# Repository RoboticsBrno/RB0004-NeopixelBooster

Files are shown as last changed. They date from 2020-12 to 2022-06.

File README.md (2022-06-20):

# RB0004 - Neopixel Booster

Probably all of us makers love WS2812B - the addressable LEDs, which are often
called "Neopixel" based on the brand created by
[Adafruit](https://learn.adafruit.com/adafruit-neopixel-uberguide). They are so
much fun to play with! Especially when you can buy them in strips for less than
18 USD/5 meters!

These LEDs are, however, power-hungry, and the strips are not the best design.
Therefore you often struggle to power them - you need a 5V power supply with
a large current rating. And these aren't easy to get. And if you get one, the
strips behave weirdly - the end of the strip has more reddish colors compared
to it's beginning.

**This is where RB0004 - Neopixel Booster comes in: it solves all the problems
above.**

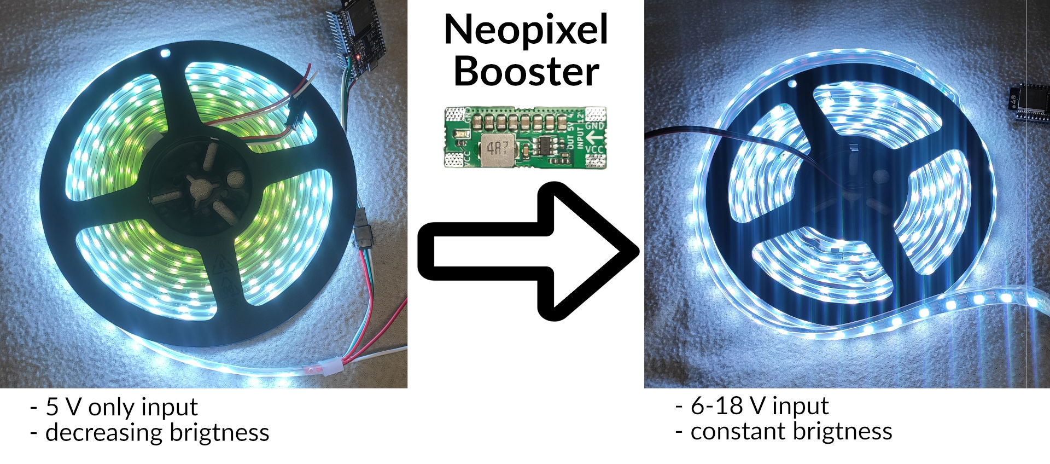
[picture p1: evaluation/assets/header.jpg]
Header


View this project on [CADLAB.io](https://cadlab.io/project/23122).

## The Problem In Short

If you are interested in much in-depth explanation of the problem with some
measurements, see the [page about strips properties](properties.md).

Each of the LEDs consumes around 60-70 mA in the full brightness (based on the
temperature and batch you have). Therefore, if you have 300 LEDs in a strip,
they will consume 18-21 A! That's a lot of current. When you push current
through a wire, there is a voltage drop according to [Ohm's
law](https://en.wikipedia.org/wiki/Ohm%27s_law). The copper wire on the strips
is relatively thin and narrow. Therefore, there will be a significant voltage
drop. It is quite common that you supply your strip with 5 V, but you will
measure only 2.5 V at the end of the strip. That means your LEDs can't shine the
full brightness.

But why they turn red? There is a red, green, and blue LED in the
chip. Each of the LED colors has a different [forward voltage
drop](https://en.wikipedia.org/wiki/LED_circuit) - the blue one has the larges
one, and it is usually around 3 V. That means if the LED is supplied with less
than 3V, it cannot light up the blue channel and thus, it is missing from the
final color.

You could solve that by just bonding a thick wire to the back of the strip.
However, a suitable wire for 21 A will be pretty thick (around 3.5 mm²).
Therefore, it is better to power the whole strip with higher voltage, thus
lower the current flowing in the wires and only lower the voltage locally for a
few LEDs. And that's what exactly Neopixel Booster does.

You run an extra wire around your LED strip and connect multiple Neopixel
Boosters in the strip to power it by segments:

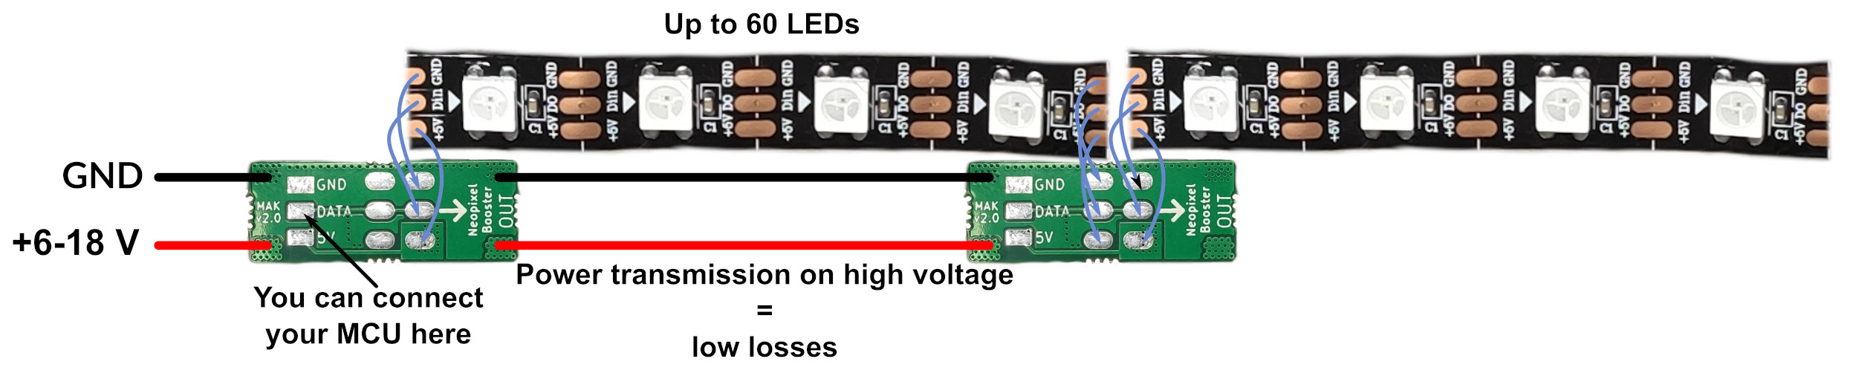
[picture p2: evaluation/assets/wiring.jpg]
Wiring diagram


## Features

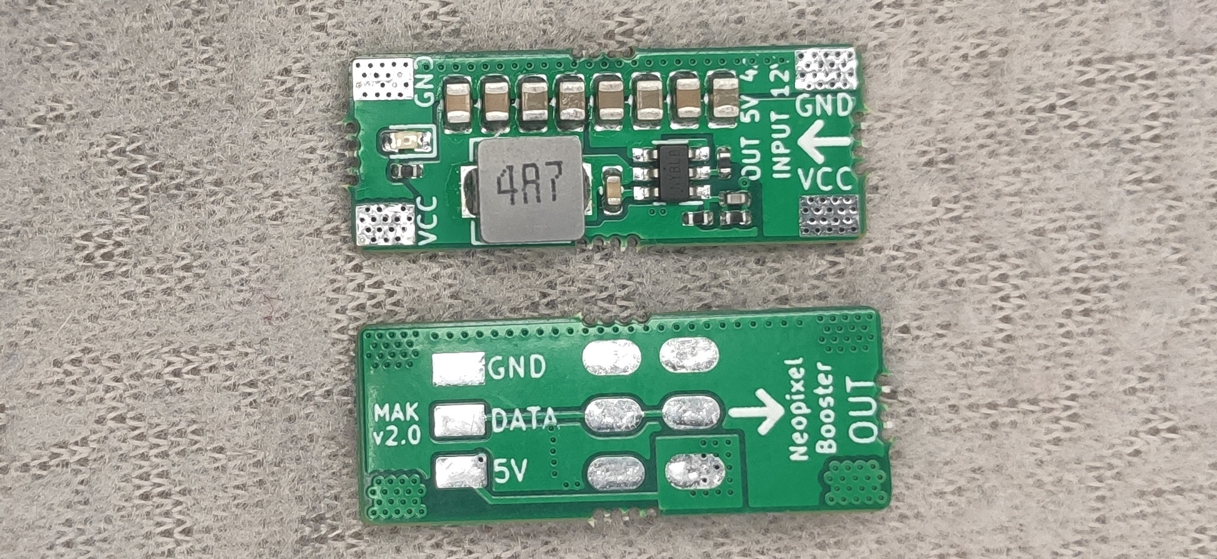
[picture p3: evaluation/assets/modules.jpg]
The photo of the modules


- **fixes the powering issue of the WS2812B LED strips on the market**
- you can power your strips with 6-18 V
    - higher voltage allows you to use thinner wires
    - when your power your strip with higher voltage, the power supply can have
      a lower current rating.
    - you can easily use a PC power supply for powering your LEDs.
    - you can easily power your strip from 2-4 Li-ion cells connected in series
- requires relatively easy modification the strip, see the [assembly
  guide](assembly.md)
- Neopixel Booster is step down module; see  [its characteristics and
  performance](https://roboticsbrno.github.io/RB0004-NeopixelBooster/eval_v2/index.html).

## I Want One!



## How Do I Use Them?

Once you buy a kit from us, follow the [assembly guide](assembly.md) , and
within an hour, you can have your boosted strips.

## How Many Do I Need Them?

We recommend not to exceed 60 LEDs per one Neopixel Booster. It is best for
convenient assembly to put one Neopixel Booster for each 50 cm of the strip, but
if you want to go cheap, it is OK to apply it every meter.

## Licence

[RB0004 –
NeopixexlBooster](https://github.com/RoboticsBrno/RB0004-NeopixelBooster) by
[Jan Mrázek](https://honzamrazek.cz) and Martin Kousal is licensed under [CC
BY-NC-SA 4.0
](https://creativecommons.org/licenses/by-nc-sa/4.0).

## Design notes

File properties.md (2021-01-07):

# Performance of the Modified Strips

As a benchmark, we choose the 5 m long strip with 60 LEDs per meter, which is
commonly available.

## The Problem With Common LED Strips

When you turn on all LEDs on the maximum brightens (RGB: 255, 255, 255) and
power it from a decent power supply you can observe the following:

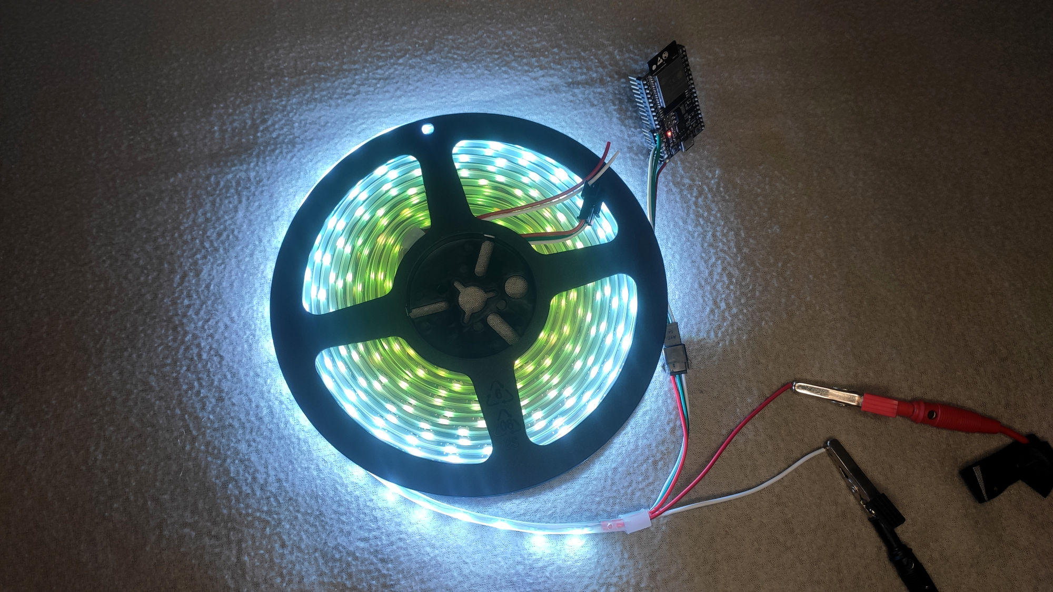
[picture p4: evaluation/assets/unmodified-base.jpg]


The end of the strip is not white, but orange/red. We power the strip from 5 V:

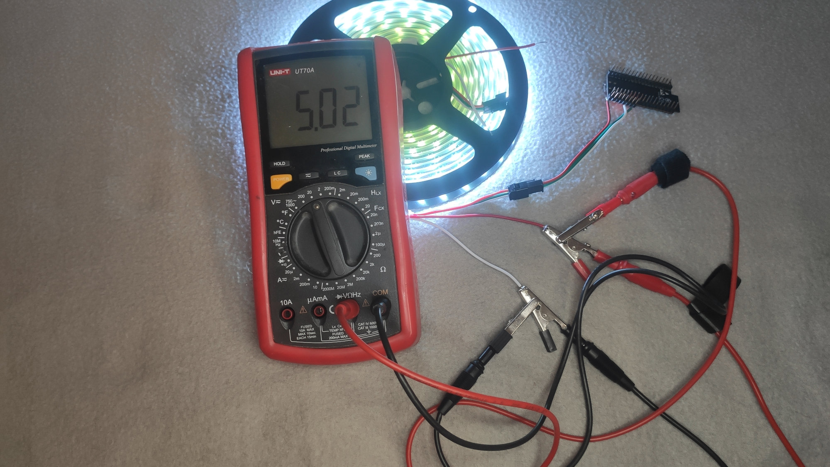
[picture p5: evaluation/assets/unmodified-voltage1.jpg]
Voltage 1


We also measure, that the strip draws only about 3.7 A instead. The low current
is suspicious: according to datasheet, each LED should draw between 60-70 mA on
full brightness. That should be 18-21 A for our strip (300 LEDs)! Let's measure
the voltage at the end of the strip: it is only 2.5 V:

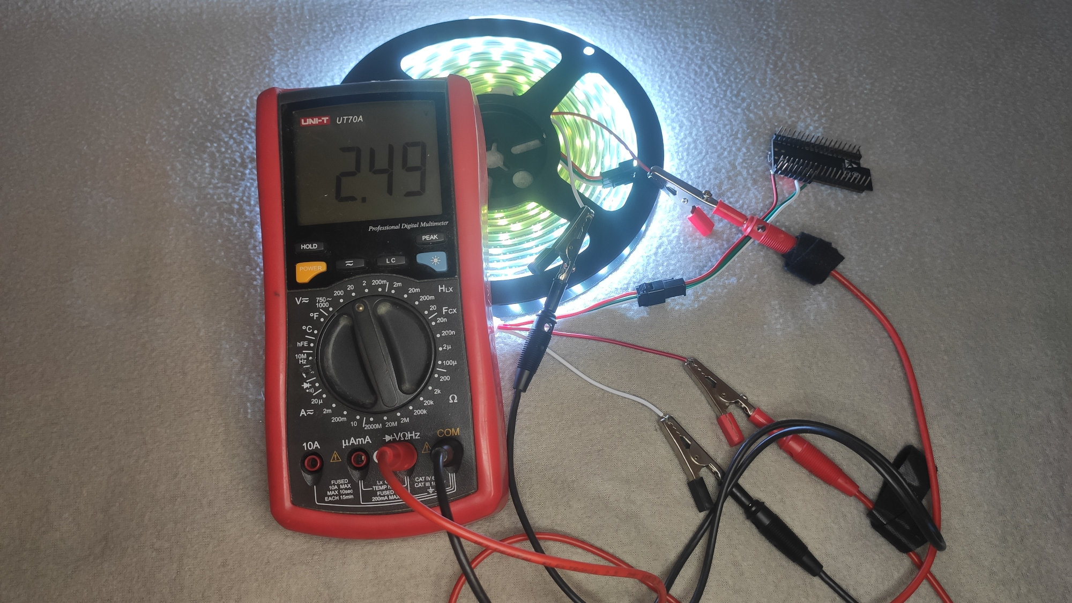
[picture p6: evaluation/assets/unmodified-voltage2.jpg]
Voltage 1


The voltage drop we observe is caused by the current flowing through the copper
traces on the flexible PCB (see [Ohm's
law](https://en.wikipedia.org/wiki/Ohm%27s_law) if you are unfamiliar with this
effect). The copper wire on the strips is relatively thin and narrow, therefore,
there is a significant voltage drop. Actually, we can try to measure the
resistance (note that this is not the ideal setup for measuring low resistance,
but it is OK for illustration purposes):

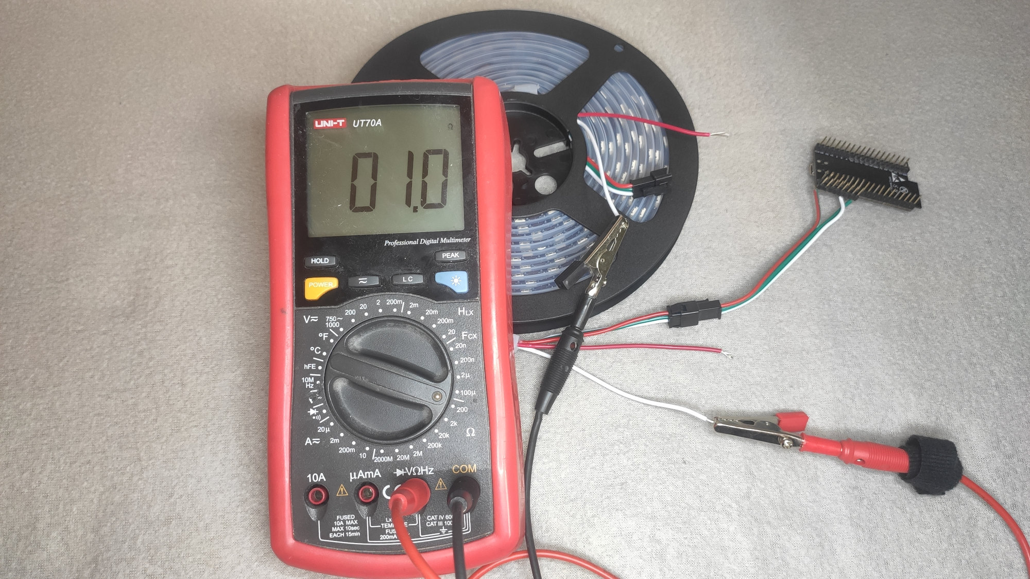
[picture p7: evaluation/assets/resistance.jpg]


It is 1 Ohm (for the GND wire, there will one more Ohm for the +5V wire). That's
a lot for a power trace. Just make sure we measure the resistance of the traces,
not our multimeter test leads:

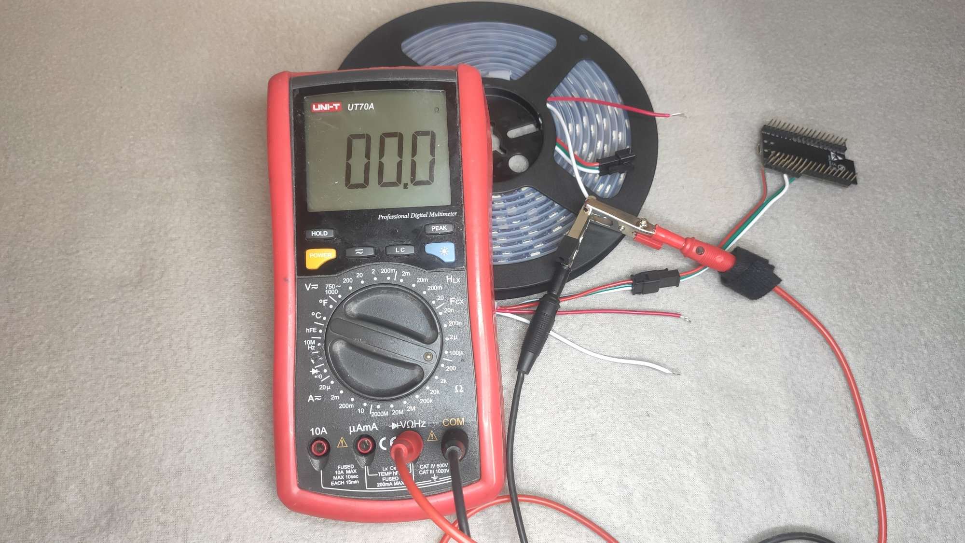
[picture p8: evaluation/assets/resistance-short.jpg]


Therefore, we can see that the voltage drops along the strip, thus, the LEDs in
the end of the strip do not have enough voltage to shine fully. But why they
turn red? There are red, green and blue LED in the chip. Each of the LED color
have different [forward voltage drop](https://en.wikipedia.org/wiki/LED_circuit) - the blue one has the larges one and it is usually around 3 V. That means if
you LED is supplied with less than 3V, it cannot light up the blue channel and
thus, it is missing from the final color.

You could solve that with just bonding a thick wire the back of the strip.
However, a suitable wire for 21 A will be pretty thick (around 3.5 mm²).
Therefore, it is better to power the whole strip with with higher voltage, thus
lower the current flowing in the wires and only lower the voltage locally for a
few LEDs. And that's what exactly Neopixel Booster does.

If your are interested in the assembly procedure for Neopixel Boosters, visit [assembly guide](assembly.md).

## Performance of the Modified Strip

We took the strip, cut it in 50cm strips and joined them with Neopixel Boosters.
The Neopixel boosters are connected via a power supply wire with 0.5 mm². We
powered the whole setup from 12 V. It shines nicely white and the color is
uniform:

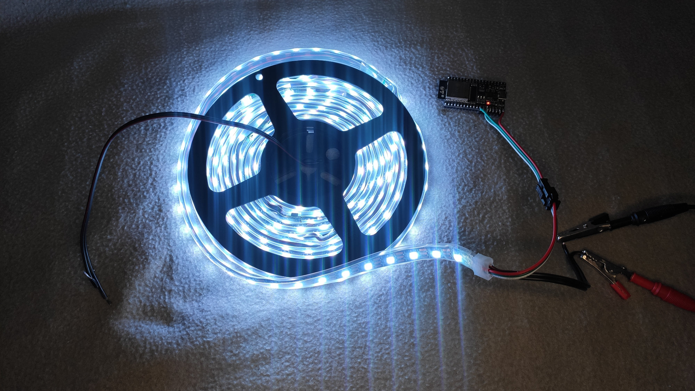
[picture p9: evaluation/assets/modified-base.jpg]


The voltage drop across the power line is roughly 0.7 V:

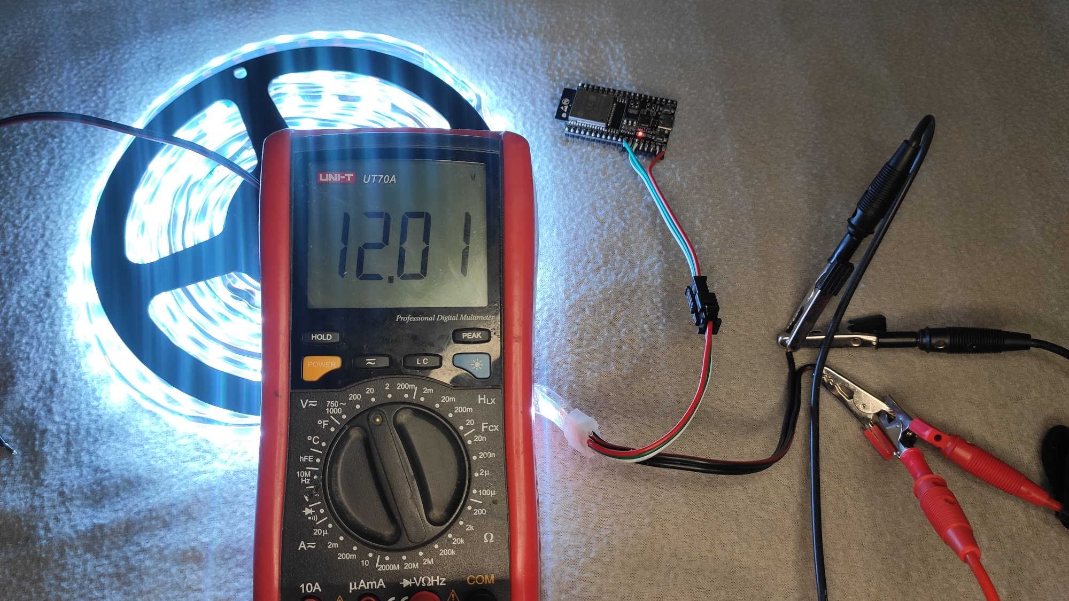
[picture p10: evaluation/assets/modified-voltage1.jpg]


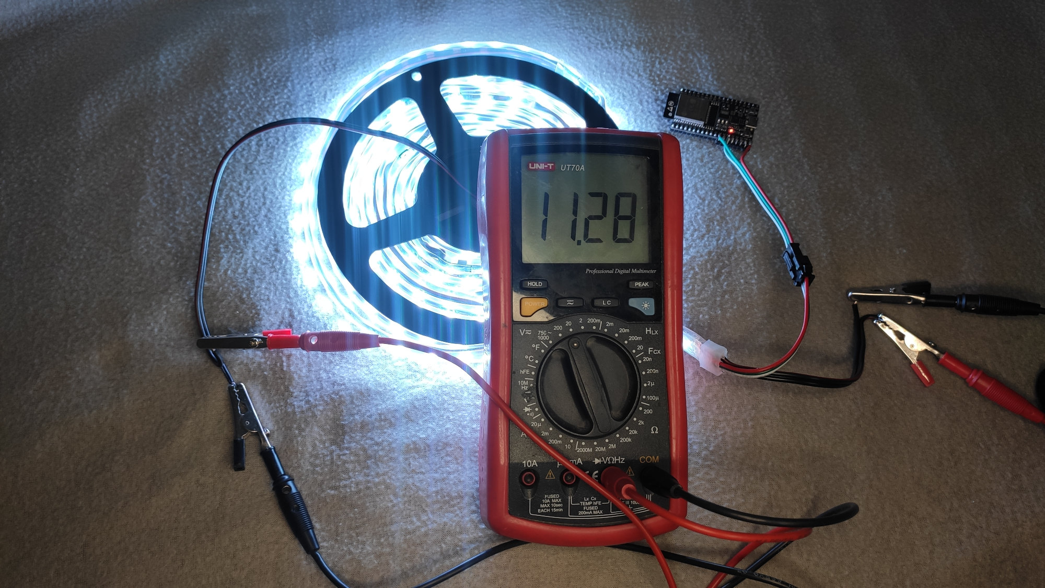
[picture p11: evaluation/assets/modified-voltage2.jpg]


And the strip consumes 5.45 A:

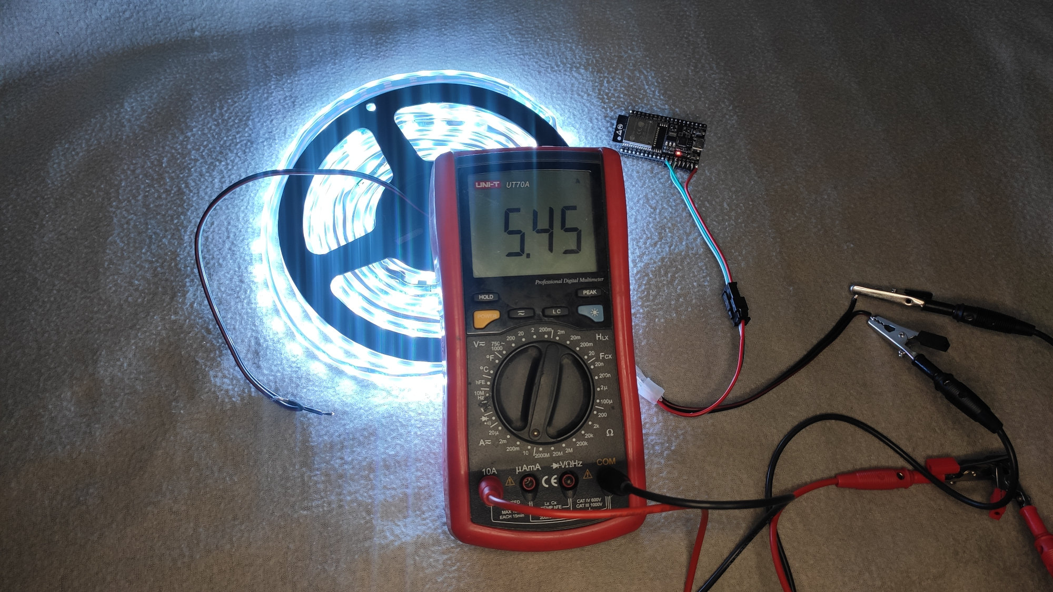
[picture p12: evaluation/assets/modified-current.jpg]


Therefore, the modified version draws 66 W, meanwhile, the original version
draws only 17.5 W (you can tell the difference in brightness clearly). If your
are interested in knowing efficiency of such solution, see [performance
characteristics](https://roboticsbrno.github.io/RB0004-NeopixelBooster/eval_v2/index.html).

[Back to the title page.](index.md)

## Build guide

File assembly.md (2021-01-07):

# Wiring Guide

The next paragraphs outline the connection of the Neopixel Booster. We also
provide your with step-by-step guide and assembly tips in the next chapter.

Neopixel Booster have the following pinout:

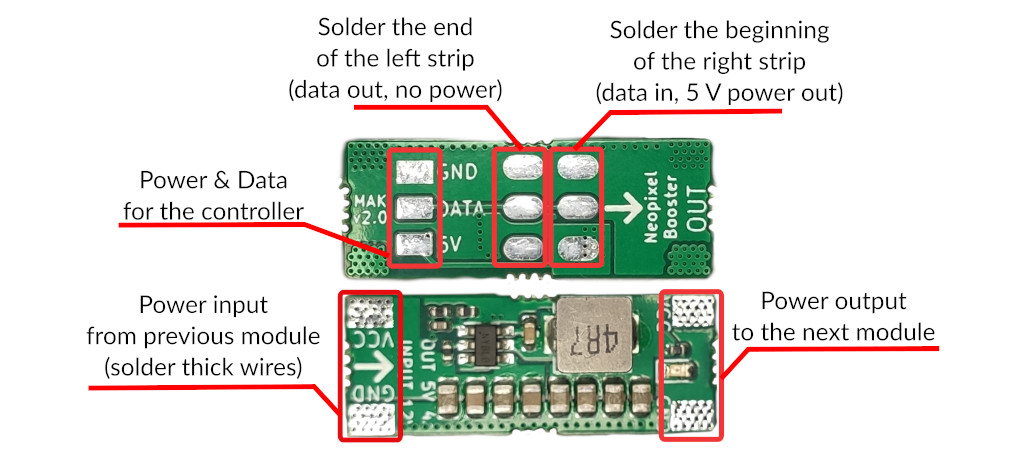
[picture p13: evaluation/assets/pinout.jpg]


Basically, to make them work, cut your LED strips into pieces and join them via
the the booster like this:

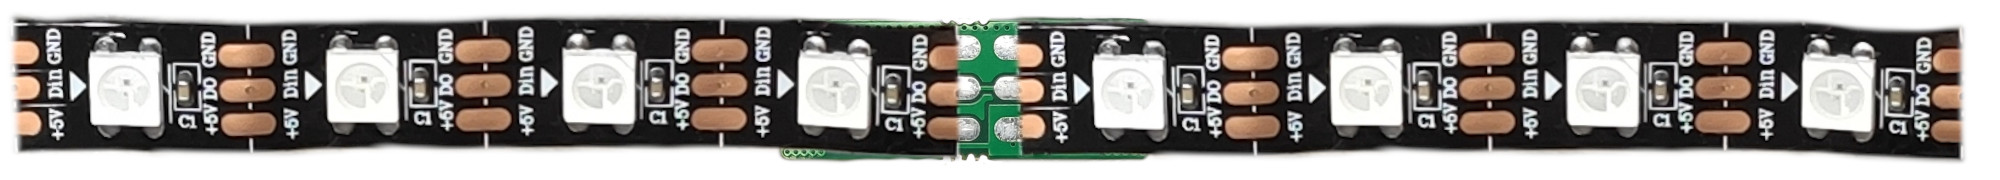
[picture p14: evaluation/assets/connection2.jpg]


And then connect the booster with a sufficiently thick wire (we recommend at
least 0.3 mm² for 5 meter strips, ideally choose 0.5 mm²) to distribute the
power to the modules. Be careful to not short the 5V pads of the strips on the
module. They need to be disconnected for proper module operation.

Note that you can use the square pads on the modules to power your MCU (e.g.,
Arduino or ESP32). You can also connect the data pin here.

How long should be the strips? It depends on you. There are a few factors to
consider:
- Noepixel Booster can deliver up to 4 A, thus we do not recommend to connect
  more than 60 LEDs to it in case you plan to use the full brightness.
- Most of the strips are made out of 50cm segment that you can easily desolder -
  there is no need for cutting.
- With longer segments, the voltage drop on the 5V line can become visible again.

Thus, in most of our installations, we put a booster for each 50cm segment of
the original strip.

A few tips:

- watch the arrows on the module and the strip so you don't accidentally solder
  your strips in reverse.
- bond your power wire to the strip for easy manipulation:
    - if you have a strip in silicone tubing, you can run the power wires
      through the tubing
    - otherwise, you can use a few rings of heat shrink tube to bond it.
- instead of wires, you can use [ribbon power
  cables](https://www.superbrightleds.com/moreinfo/power-wires-cables/flat-power-wire-10mm/1528/3555/)
  to make the whole assembly flat.

# Step-by-step Guide

In this guide we will walk you through the rebuild of the "IP66 60 LED/m LED
strip" - it is the LED strip with a silicone tubing. Our goal is to change its
appearance as least as possible.

First, note that the strip consists out of 50cm segments which are soldered
together.

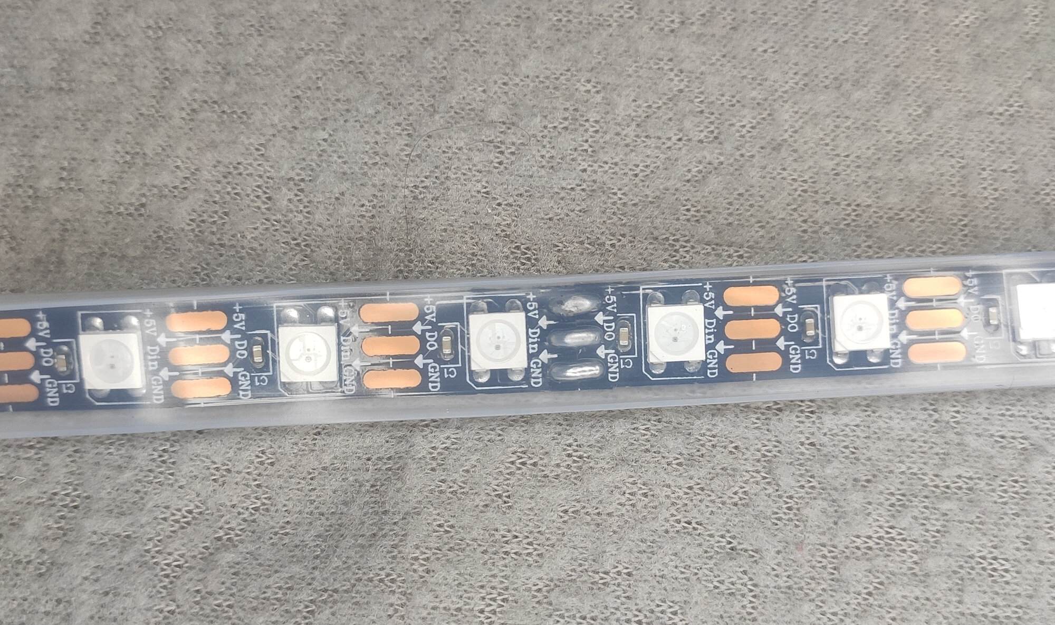
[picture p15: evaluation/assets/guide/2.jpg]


This is the place where we will cut the tubing, desolder the strips and join
them with a booster module.

Let's start with the beginning of the strip where is the power in and data
connector. It is a bunch of wires sealed by hot glue:

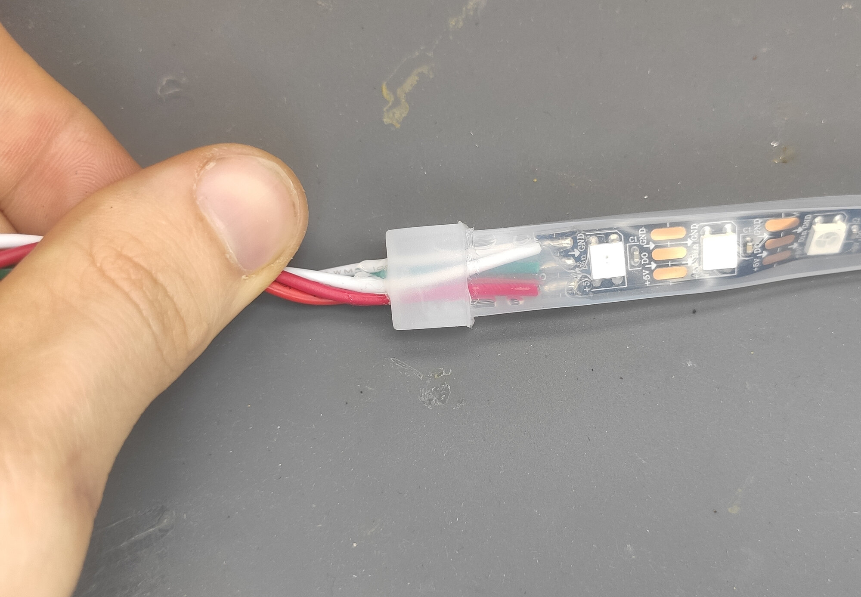
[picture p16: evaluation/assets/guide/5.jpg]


We will solder the booster like this to the strip:

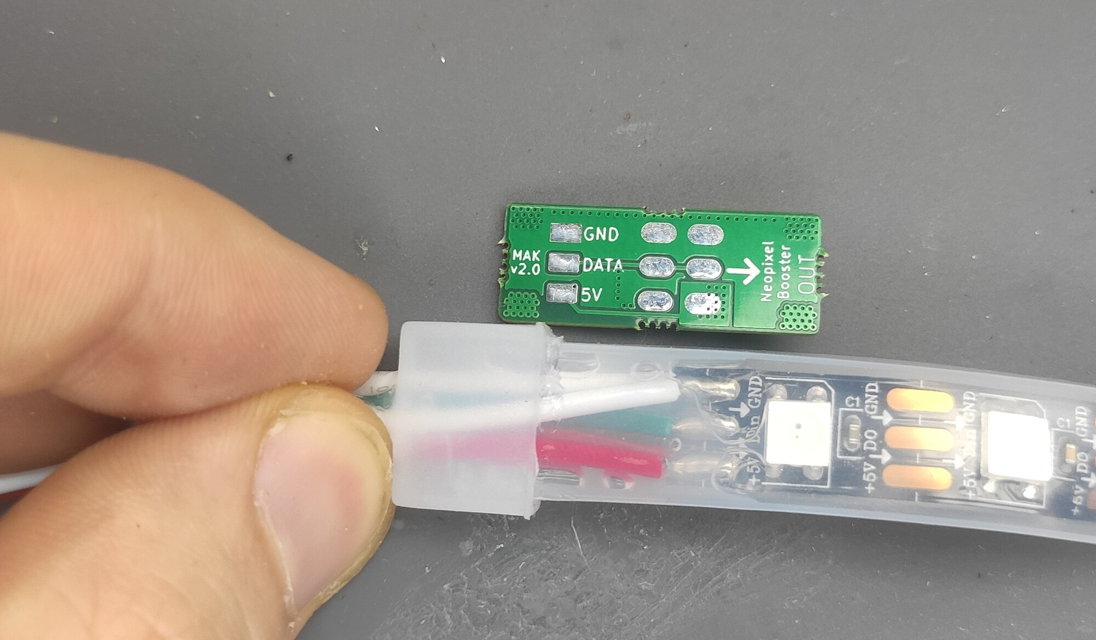
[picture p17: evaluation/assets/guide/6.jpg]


Start by carefully pulling the end cap. With enough force, the hot glue will
become loose:

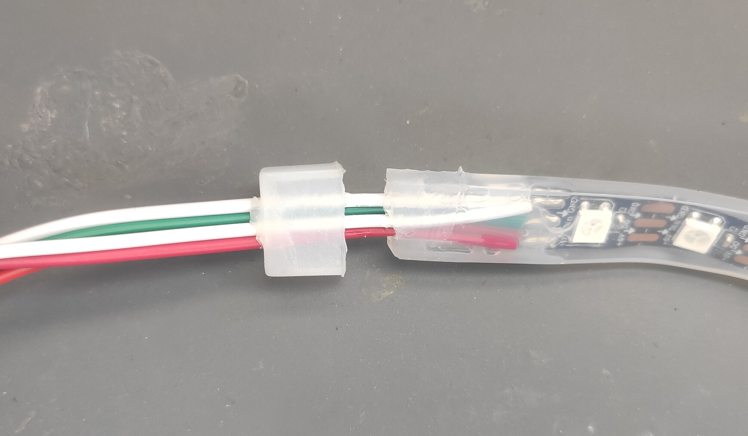
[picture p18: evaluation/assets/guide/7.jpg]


Then put the silicone tubing aside:

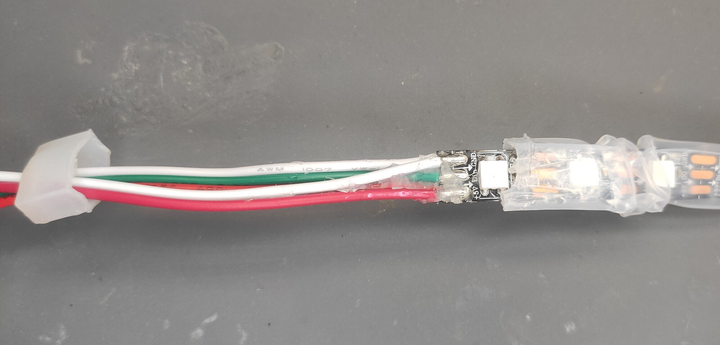
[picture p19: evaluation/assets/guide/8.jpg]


Next, we will move to the end of the first segment. Locate the solder joint and
cut the silicone tubing:

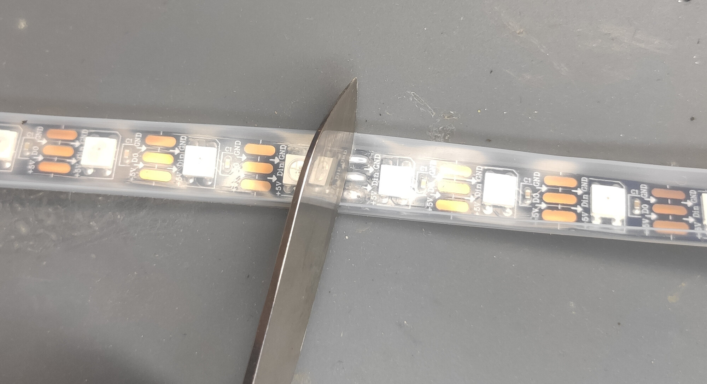
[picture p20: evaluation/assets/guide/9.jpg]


So you expose the solder joint:

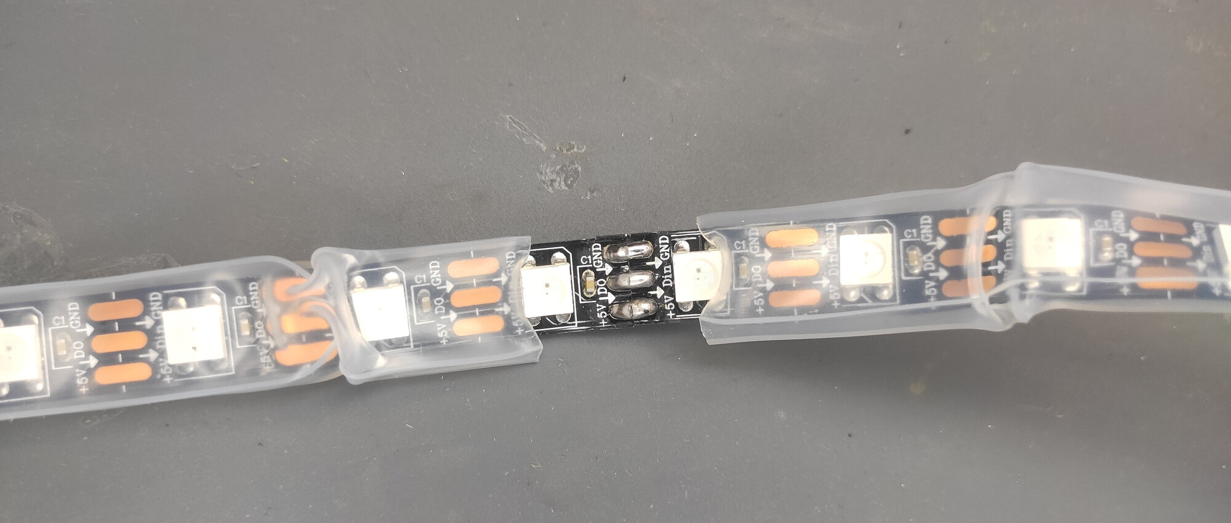
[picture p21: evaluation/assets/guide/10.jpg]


Then, take your soldering iron and desolder the segments:

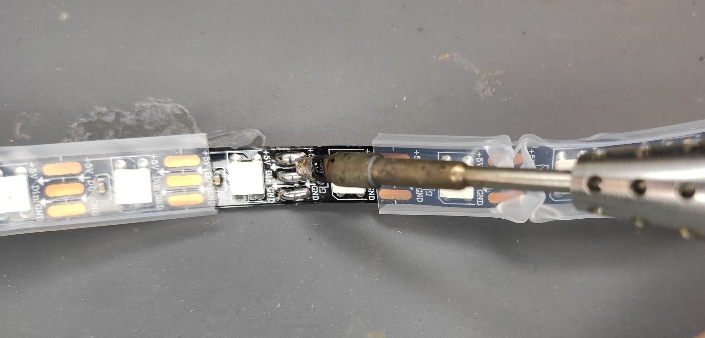
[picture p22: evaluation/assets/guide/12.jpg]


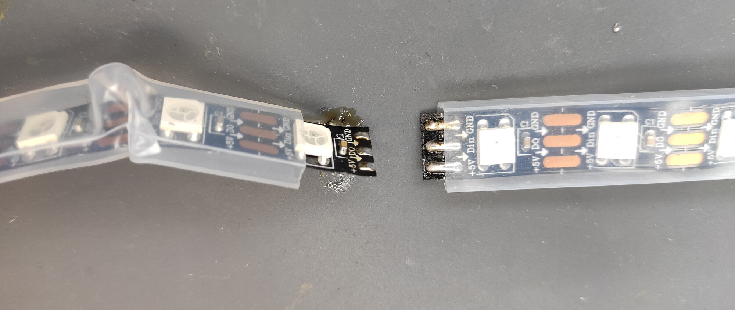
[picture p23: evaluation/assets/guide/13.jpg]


You should have a segment like this:

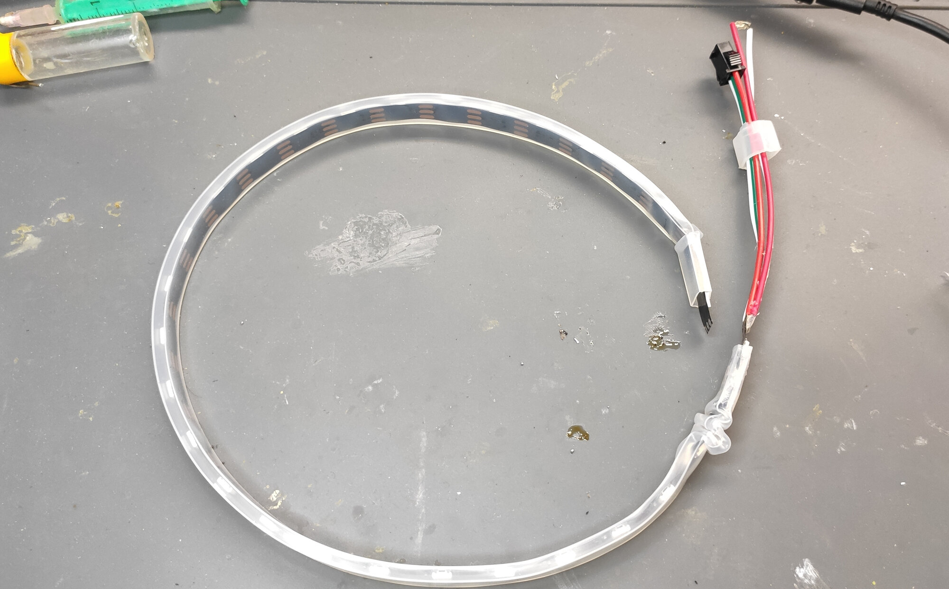
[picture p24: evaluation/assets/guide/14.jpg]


Now, desolder the original supply wires from the beginning of the connector:

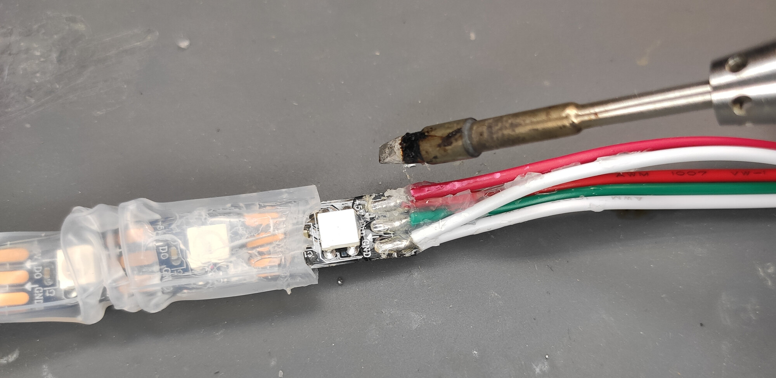
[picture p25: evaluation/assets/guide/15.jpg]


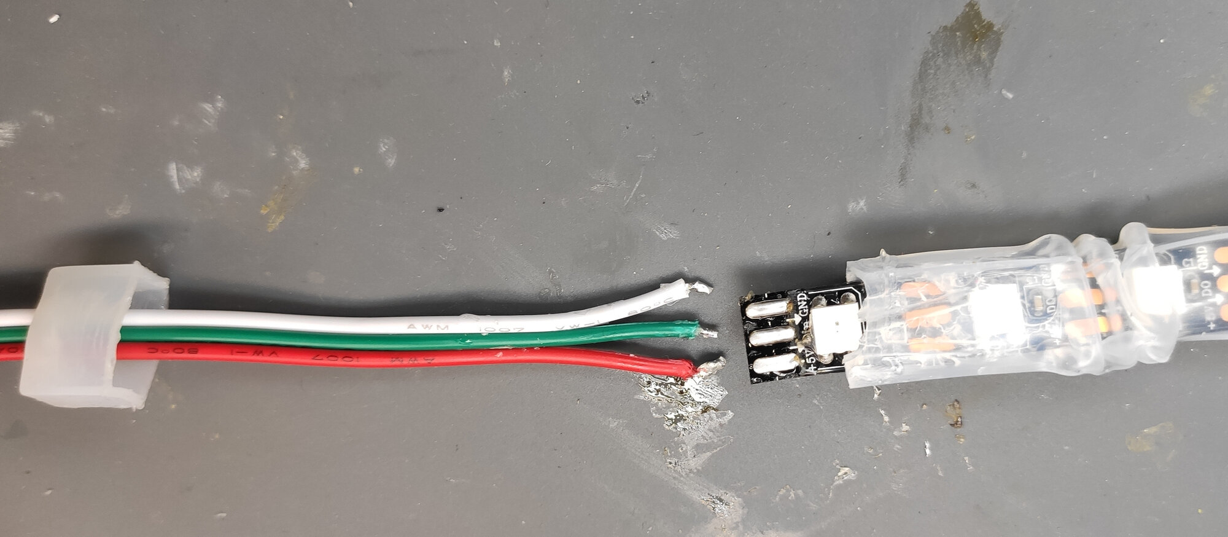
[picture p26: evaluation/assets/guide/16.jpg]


Turn the strip to the back side - there will be exposed pads:

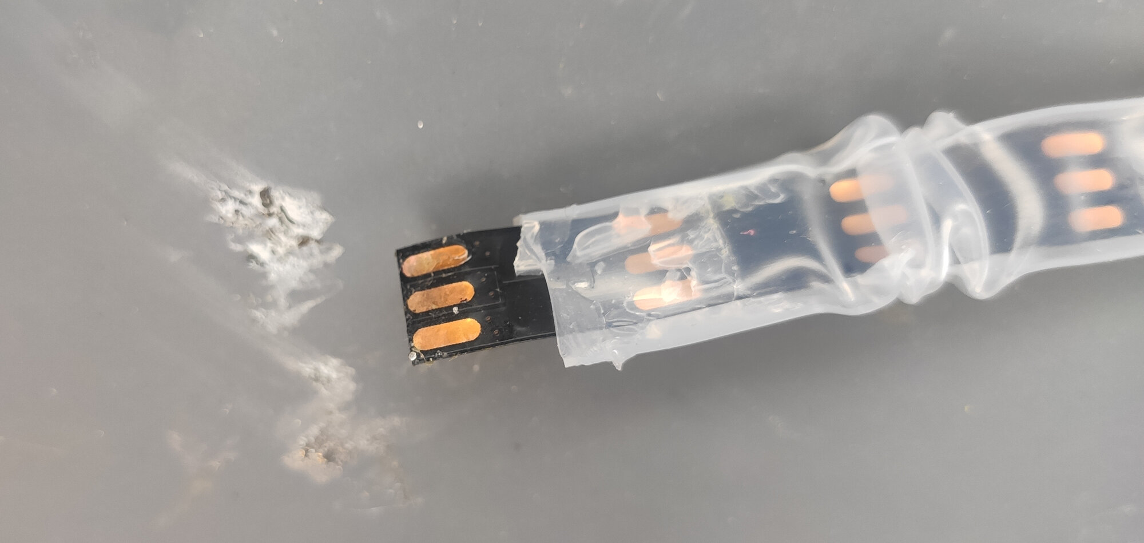
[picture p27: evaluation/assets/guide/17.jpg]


Put solder on them so they are covered in solder from both sides (this helps the heat transfer in the following soldering process):

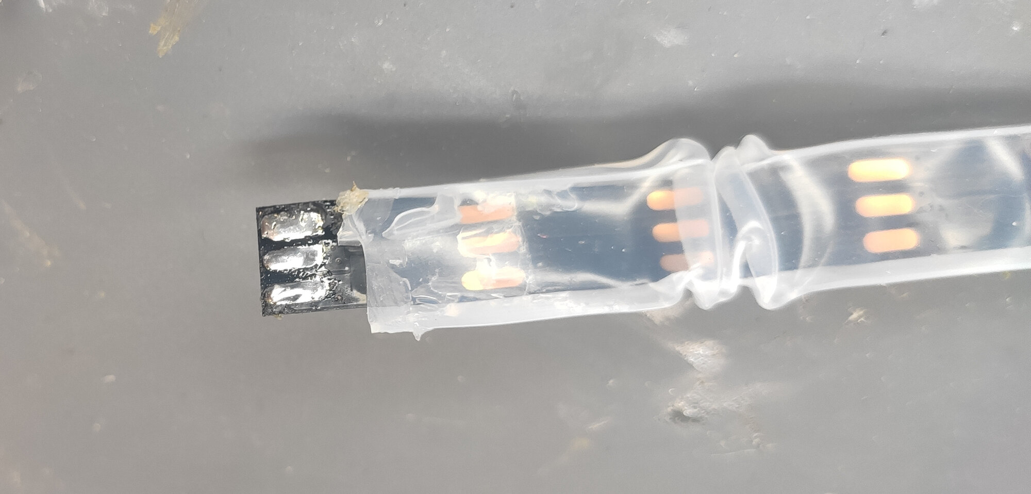
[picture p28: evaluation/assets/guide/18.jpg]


Now, solder the module to the strip. The best way to do so is to first put
solder on the pads on the module, apply a little flux on the bottom of the
strip, put it in place and heat it from above. Also, solder the original supply
wires to the square pads on the module:

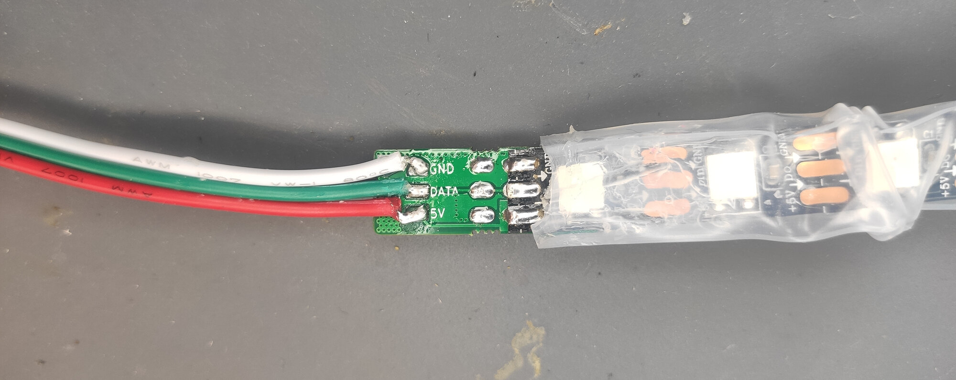
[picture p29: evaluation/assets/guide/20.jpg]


The next step is to add power wire along the segment. We will put it inside the
tubing. This could look impossible at the beginning, but there are two ways
which makes the procedure easy.

The first one is to put a solid rod inside the tubing, so it can't bend. Then
you push thin wire though it. Remove the rod,  solder the think wire to the end
of the thick wire and then just pull the thin wire out:

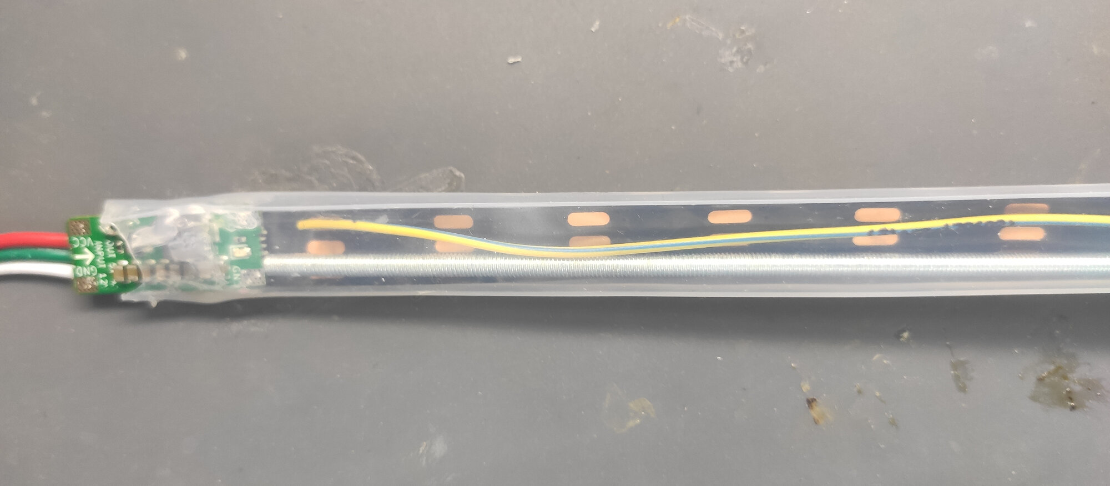
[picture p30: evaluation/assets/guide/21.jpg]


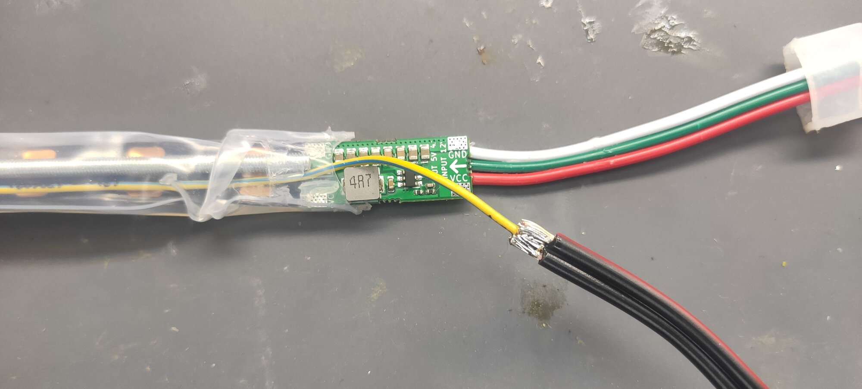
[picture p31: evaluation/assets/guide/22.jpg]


The second method is to use 1mm thick steel wire that is long at least as the
segment. Bend a small hook on one end. Then connect use the hook to pierce the
insulation of the supply wire. And now just run the steel wire through the
tubing.

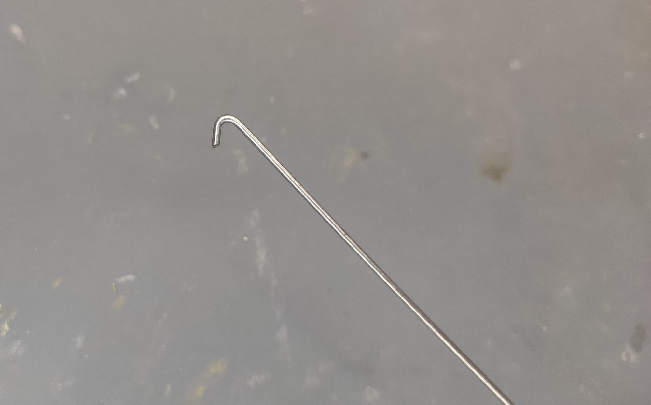
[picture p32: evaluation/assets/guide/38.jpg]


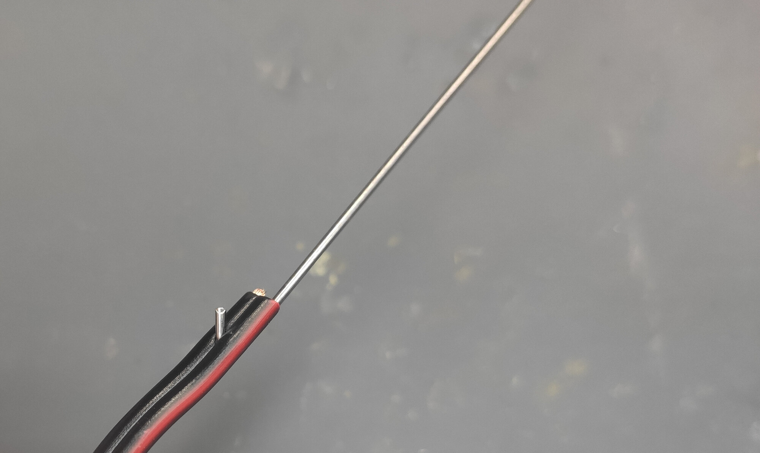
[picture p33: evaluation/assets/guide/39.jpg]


Now, solder the power wires to the modules. Be aware of the polarity.

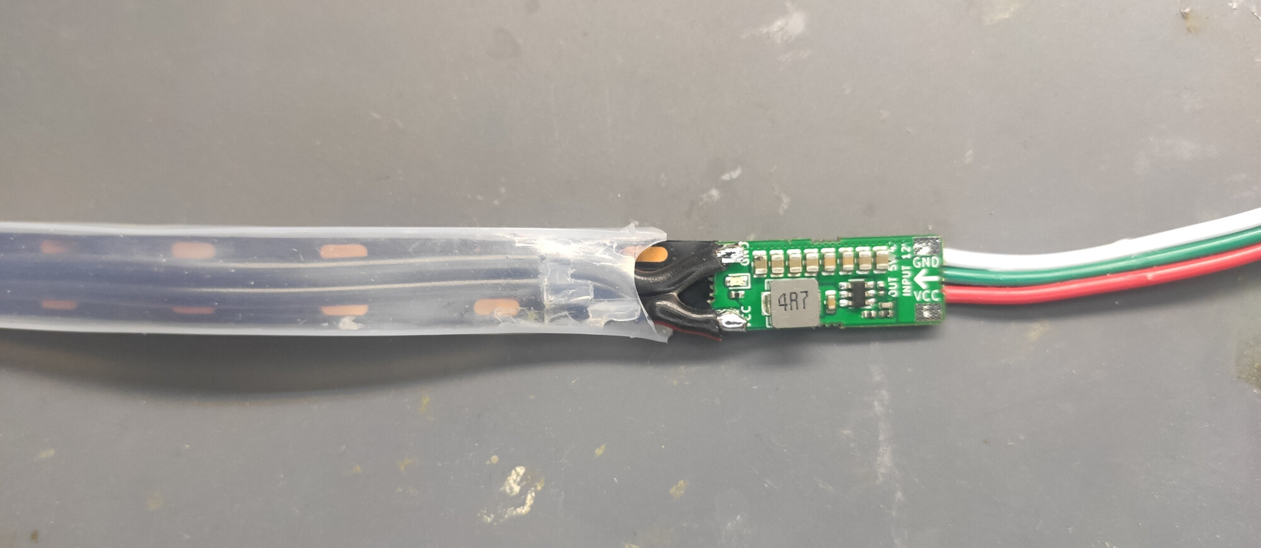
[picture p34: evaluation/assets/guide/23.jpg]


Now, solder power wires on the other side of the modules - this will be the new
leads via which you power your strip.

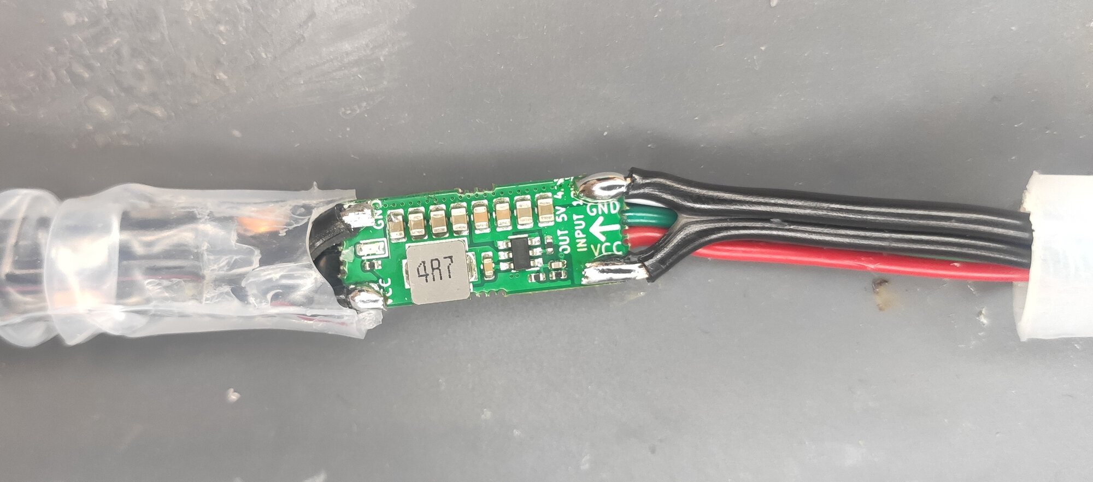
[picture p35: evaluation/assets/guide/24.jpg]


Finally, you can put the cap back on. If you aim for waterproofness, use hot
glue to attach it in place.

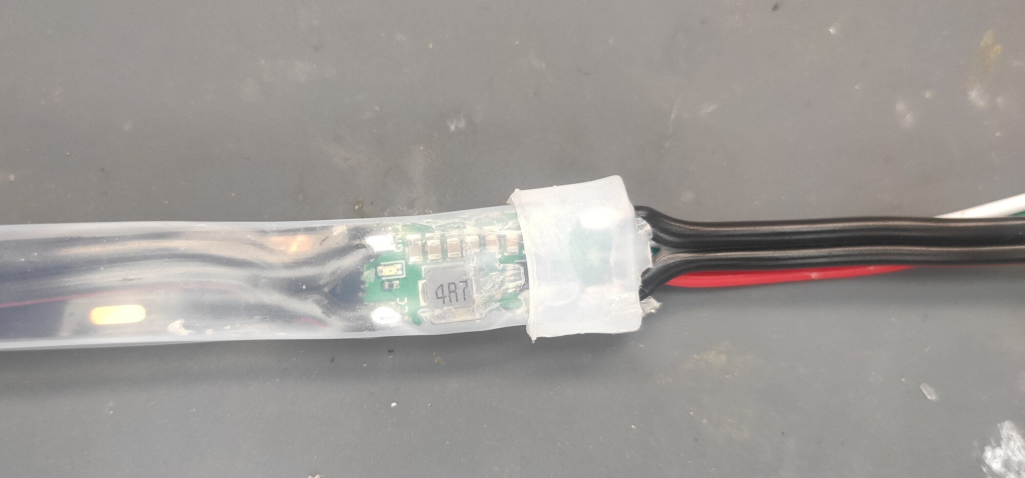
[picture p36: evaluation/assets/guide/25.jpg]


Now put a 2cm piece of ⌀12 mm heat-shrink tube. We will use it to cover the cut
in the silicone tubing.

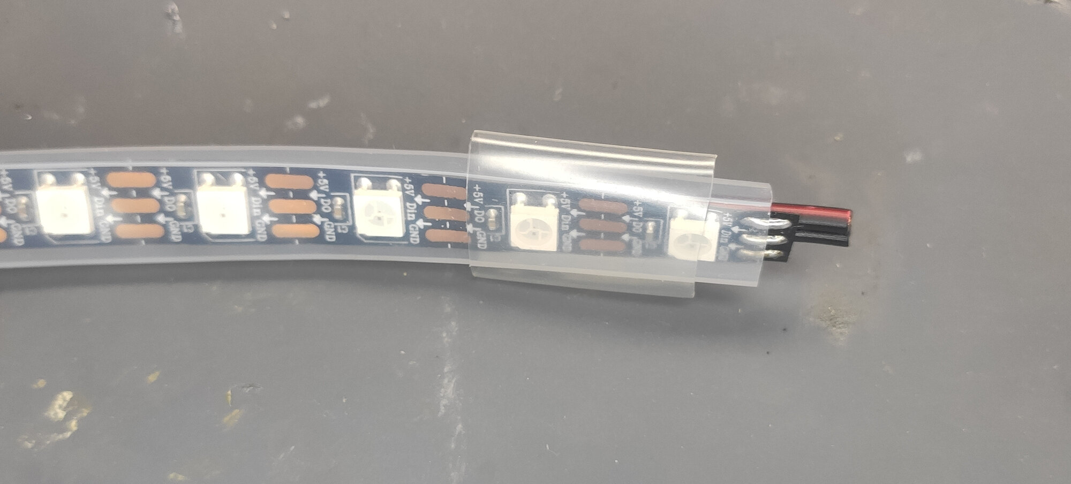
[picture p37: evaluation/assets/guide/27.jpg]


Then solder another Neopixel Booster to the end of the segment:

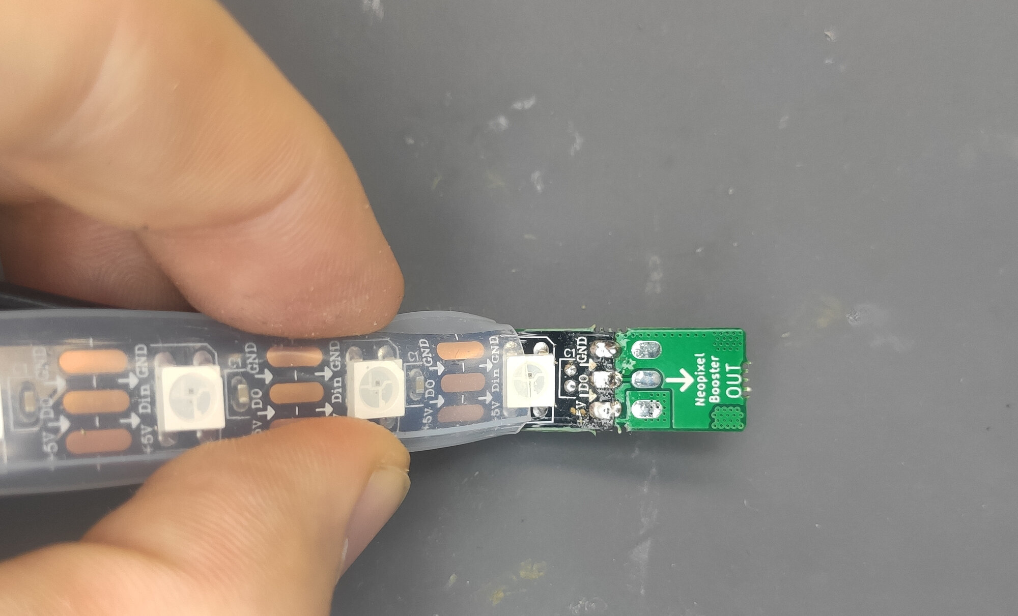
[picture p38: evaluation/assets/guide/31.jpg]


And also solder the power wires:

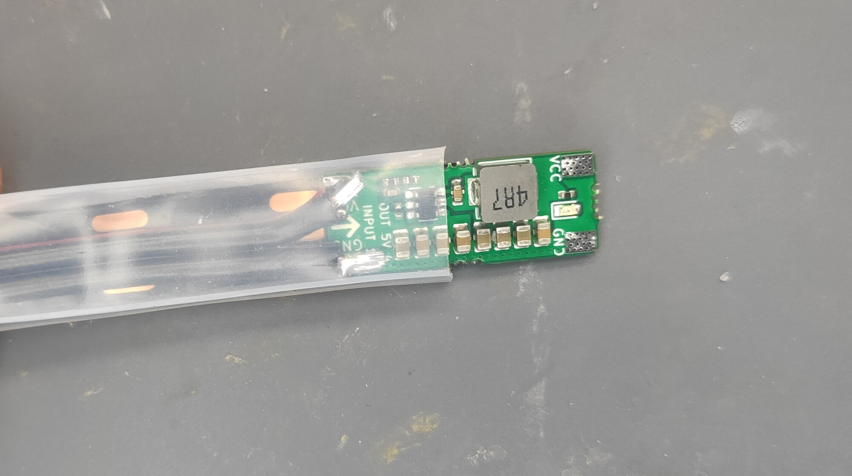
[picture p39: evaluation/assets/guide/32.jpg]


Next, solder the next segment to the module. Do not forget to run power wire thought the silicone tubing first.

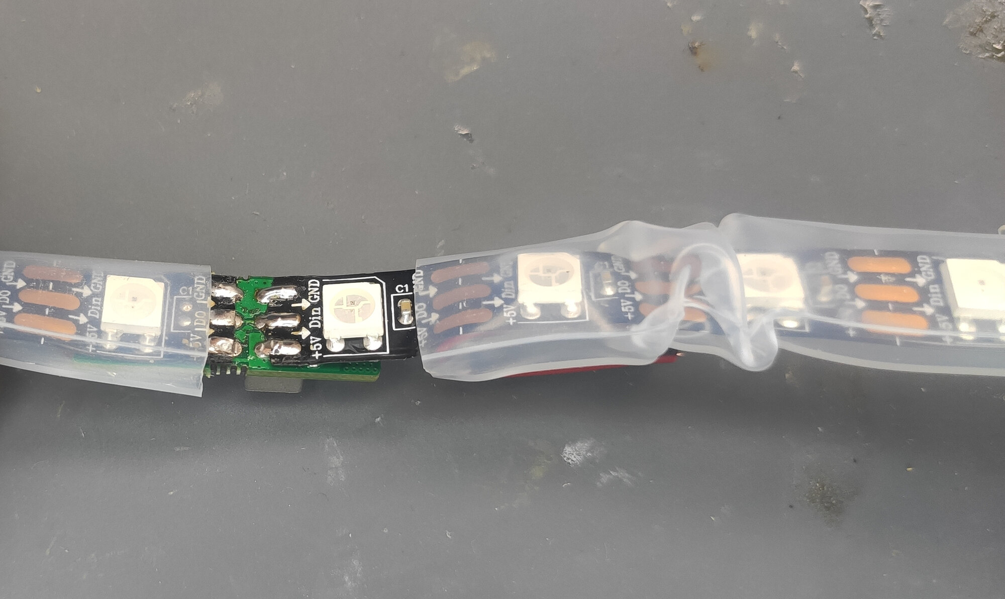
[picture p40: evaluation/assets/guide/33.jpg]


Then you can slide the silicone tubing back in:

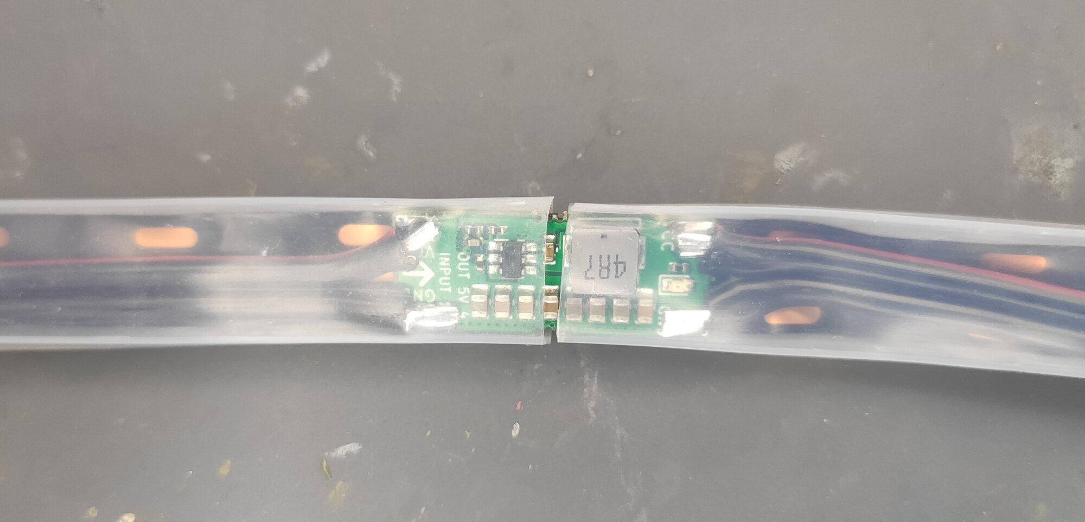
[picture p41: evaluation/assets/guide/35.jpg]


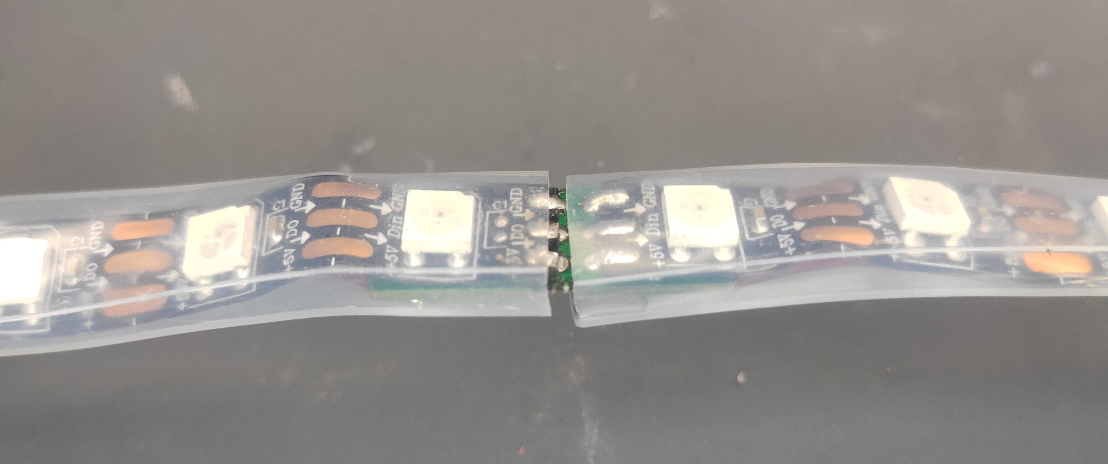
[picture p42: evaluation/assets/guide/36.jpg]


Lastly, put the heat shrink tube on the joint and seal it.

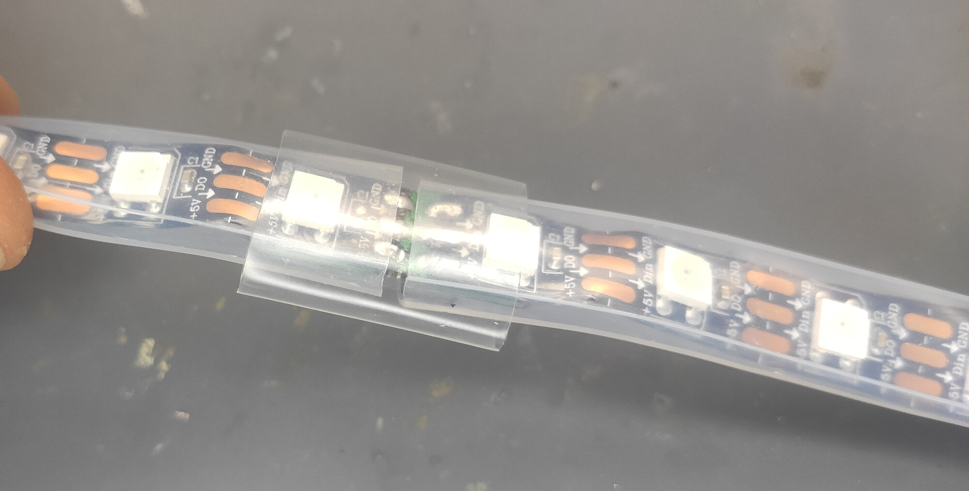
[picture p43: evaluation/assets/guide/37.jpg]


Now, just continue with rest of the segments and you are done. The whole 5m
strip took roughly an hour to upgrade completely.

[Back to the title page.](index.md)

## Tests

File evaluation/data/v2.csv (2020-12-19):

Input voltage @ V | Load @ A | Input current @ A | Output voltage @ V | Coil temperature after 5 minutes @ °C | Chip temperature after 5 minutes @ °C | Scope image | Noise - Vpp @ mV
12 | 0.5 | 0.226 | 5.109 | 22 | 22 | v2_1.png | 40
12 | 1 | 0.445 | 5.098 | 25 | 24 | v2_2.png | 40
12 | 2 | 0.893 | 5.094 | 26 | 28 | v2_3.png | 80
12 | 3 | 1.369 | 5.095 | 33 | 39 | v2_4.png | 120
12 | 4 | 1.874 | 5.102 | 45 | 68 | v2_5.png | 140
8.4 | 0.5 | 0.312 | 5.112 | 22 | 22 | v2_6.png | 50
8.4 | 1 | 0.624 | 5.105 | 22 | 23 | v2_7.png | 50
8.4 | 2 | 1.267 | 5.105 | 25 | 27 | v2_8.png | 70
8.4 | 3 | 1.942 | 5.11 | 31 | 34 | v2_9.png | 120
8.4 | 4 | 2.658 | 5.13 | 40 | 43 | v2_10.png | 150
8.4 | 5 | 3.46 | 5.13 | 64 | 68 | v2_11.png | 170

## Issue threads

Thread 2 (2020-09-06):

Issues of v1.0

yaqwsx, 2020-09-06:
- mousebites use large drill bit, make it smaller
- C1 LCSC Part # points to inductor, instead of capacitor
- C2 (bootstrap cap) should be at least for 25 V
- C4 (output cap)  should be at least for 10 V, better for 16 V

TBA

yaqwsx, 2021-01-07:
Resolved in 41ce3b43a9e9c91129c52add028cfa983298a6b0

Closed 2021-01-07.

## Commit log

2020-07-15 First part of schematic for stepdown
    [neopixelBooster.kicad_pcb, neopixelBooster.sch]
2020-07-16 Finish schematic, maybe finish routing
    [neopixelBooster.kicad_pcb, neopixelBooster.sch]
2020-07-16 Finish routing v1.0
    [neopixelBooster.kicad_pcb, neopixelBooster.sch]
2020-07-19 Rename MFR field to LSCS
    [neopixelBooster.sch]
2020-07-19 Use LSCS numbers
    [neopixelBooster.sch]
2020-07-20 Change output capacitor size from 0603 to 0805
    - Reroute board to optimize current path from inductor to output
    - Add makefile
    [neopixelBooster.kicad_pcb]
2020-08-10 Add tooling holes
2020-08-12 Fix assembly data
    [neopixelBooster.kicad_pcb, neopixelBooster.sch]
2020-09-29 Fixed errors of version 1.0
    - C1 changed LCSC code
    - C2 changed to 0603 100nF/50V
    - C4 changed to 0805 22uF/25V
    [neopixelBooster.kicad_pcb, neopixelBooster.sch]
2020-12-19 Draft web presentation
    [v2.csv]
2020-12-19 Initial layout of v2.0
    - Increased size of board to 26 x 10 mm
    - Swap pins for connecting Neopixel strip
    - Add filtration to input and output
    - Change shape of input pads
    [neopixelBooster.kicad_pcb, neopixelBooster.sch]
2020-12-19 Chang polygons priorities and beautify them, add more vias
    [neopixelBooster.kicad_pcb]
2020-12-19 Remov some vias due to clearance, add fancy arrow to silkscreen
    [neopixelBooster.kicad_pcb]
2020-12-19 Add polygon to inductor input
    [neopixelBooster.kicad_pcb]
2020-12-19 Fixed polygon priority, add voltage of capacitors to schematic
    [neopixelBooster.kicad_pcb, neopixelBooster.sch]
2022-06-20 Bump project to KiKit v1 and KiCAD 6
    [neopixelBooster.kicad_pcb, neopixelBooster.kicad_sch, neopixelBooster.sch]
